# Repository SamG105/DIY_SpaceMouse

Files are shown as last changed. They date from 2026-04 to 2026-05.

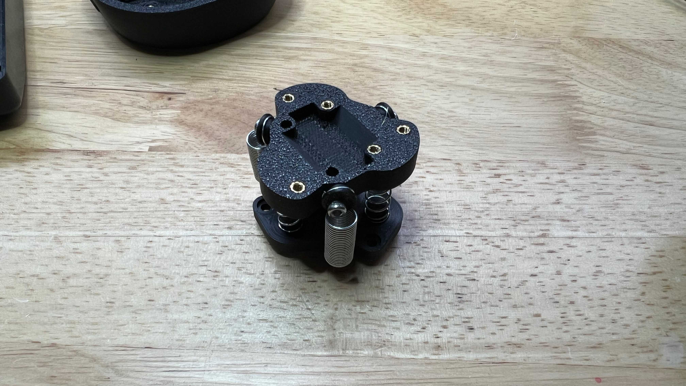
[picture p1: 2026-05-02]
Spacemouse - 1.jpeg

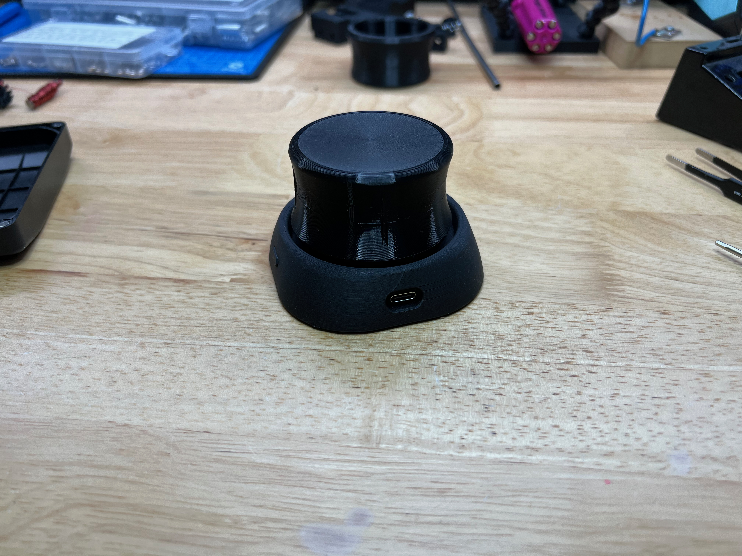
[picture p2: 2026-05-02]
Spacemouse - 2.jpeg

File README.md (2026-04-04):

# DIY SpaceMouse
A DIY SpaceMouse inspired my sb_ocr 's spacemouse build. Altough heavily inspired and based on sb_ocr's work, i designed all the files myself. 

I designed this to make the top "cap" less tall and to accomodate the Seeed studio Xiao RP2040 microcontroller as that's what i could get my hands on. I also changed the code to be purely rotation and zoom as the magnetic sensor (the TLV493D) doesn't have enough DOF to track the full pitch, yaw, roll, zoom, and pan. The code currently only measures zoom, pitch and yaw, which I have found to be the most important movements to replicate.

PLease note that the code is still a work in progress at this point. The buttons still need work to get working reliably and I've started to implement the code to make my DIY spacemouse compatible with the official spacemouse driver.

The hardware required other than the 3d prints is:
•16x M2.5 X 6mm screws
•2x M2.5 X 4mm screws
•2x 10X3mm magnets
•3x 7.14X19.05mm compression springs
•3x 7.93X28.5mm extension springs
•18x M2.5X3.5X4mm heatset inserts

Electronics:
•Seeed Xiao RP2040
•TLV439D sensor
•2x "long" tactile switches

Assembly is fairly straitfoward, simply add threaded inserts (be carefull about the side for the magnetic sensor, it only has two screws that go on one side) and then assemble like the 3d model.

I used the Arduino IDE to flash the code. you will need the "Arduino Mbed OS RP2040 Boards" Package by the official Arduino account.

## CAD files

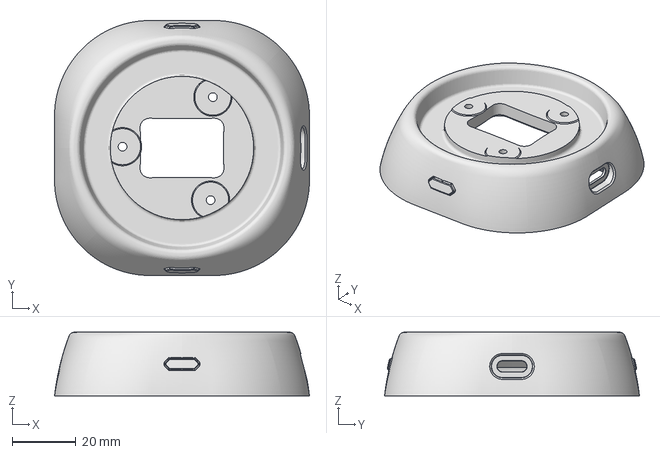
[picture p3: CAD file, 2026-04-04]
3D_Model/print files/Base/Base_body.3mf
80.0 x 80.0 x 20.0 mm

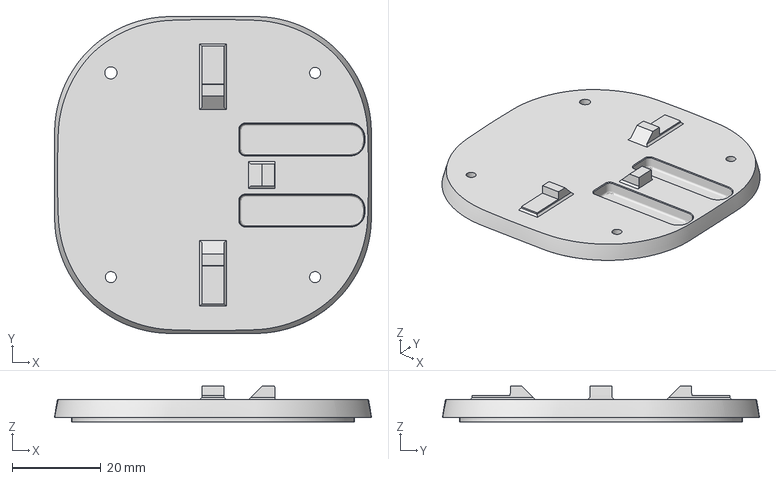
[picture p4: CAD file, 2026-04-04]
3D_Model/print files/Base/Bottom cover.3mf
71.4 x 71.4 x 8.00 mm

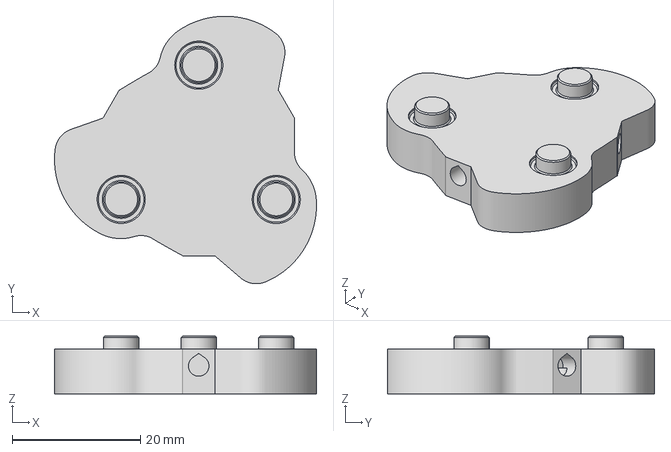
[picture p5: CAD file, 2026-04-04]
3D_Model/print files/Top cap/Bottom spring support plate.3mf
40.8 x 41.7 x 9.00 mm

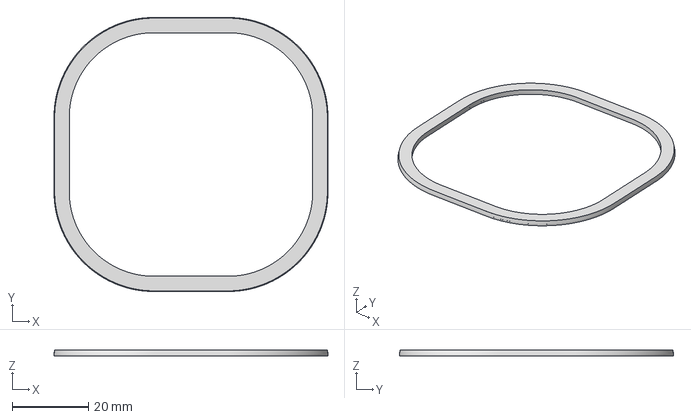
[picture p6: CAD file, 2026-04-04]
3D_Model/print files/Base/TPU anti-skid ring.3mf
71.7 x 71.7 x 1.50 mm

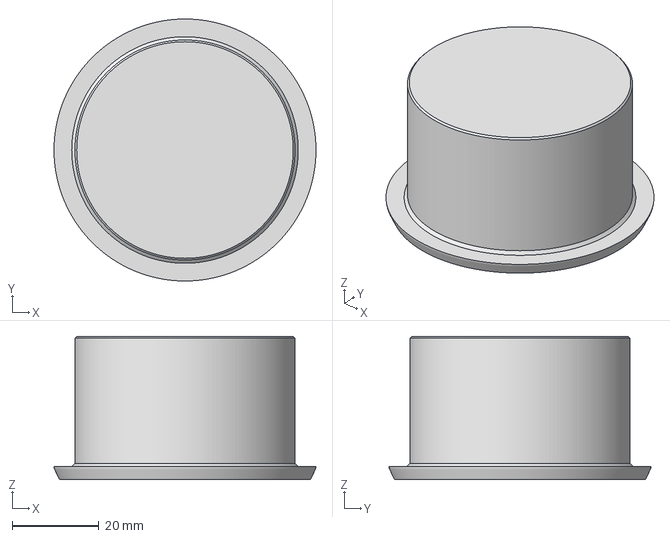
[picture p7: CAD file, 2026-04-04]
3D_Model/print files/Top cap/Inner structure.3mf
60.5 x 60.5 x 33.0 mm

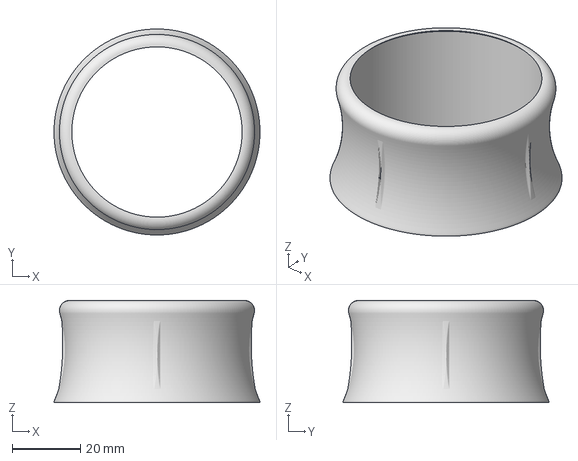
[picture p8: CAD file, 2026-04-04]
3D_Model/print files/Top cap/TPU_exterior.3mf
60.5 x 60.5 x 30.0 mm

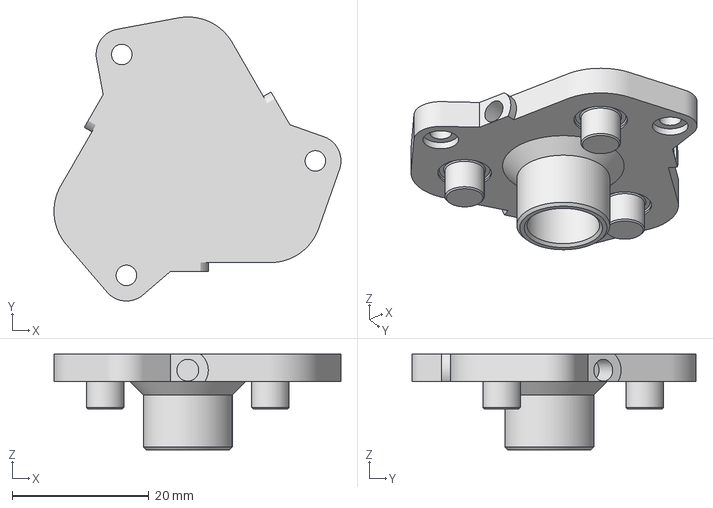
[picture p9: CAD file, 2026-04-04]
3D_Model/print files/Top cap/Top spring support plate.3mf
42.0 x 41.6 x 14.0 mm

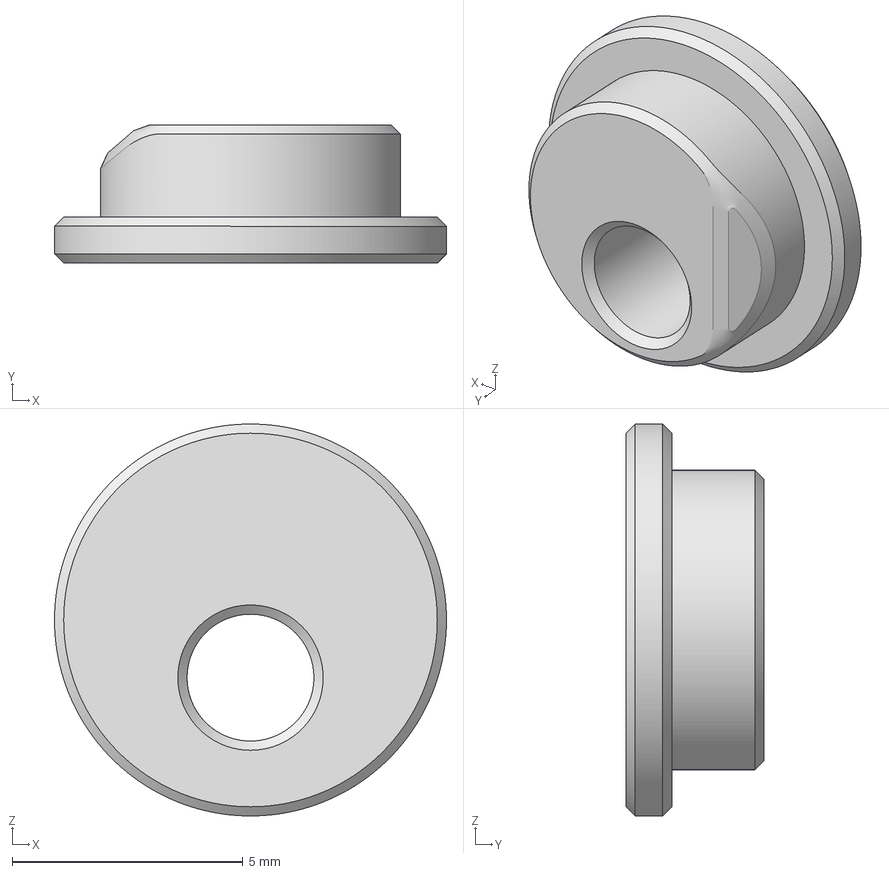
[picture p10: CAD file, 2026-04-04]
3D_Model/print files/Top cap/top spring washer.3mf
8.50 x 3.00 x 8.50 mm

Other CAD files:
3D_Model/Spacemouse_3D_model.f3z

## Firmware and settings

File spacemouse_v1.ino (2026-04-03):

#include <OneButton.h>
#include <Keyboard.h>
#include <Mouse.h>
#include <SimpleKalmanFilter.h>
#include <TLx493D_inc.hpp>

// Definitions for the magnetometer
using namespace ifx::tlx493d;

  //Definition of the pwoer pin and sensor object
const uint8_t POWER_PIN = 7;
TLx493D_A1B6 mag(Wire, TLx493D_IIC_ADDR_A0_e);

//define the kalman filter
SimpleKalmanFilter xFilter(.3,.5,0.1), yFilter(.3,.5,0.1), zFilter(.3,.5,0.1);

//Definitions for the buttons
#define BUTTON_1_PIN 1
#define BUTTON_2_PIN 2

  // define button objects
OneButton button_1;
OneButton button_2;

// global variables
float xHome = 0, yHome = 0, zHome = 0;
float x = 0, y = 0, z = 0;

// constants
const float xyDeadzone = .3;
const float zDeadzone = .15;
const float zThreshold = .5;
int calibrationSamples = 300;
bool isOrbit = false;
double sensitivity = 0.25;
double zSensitivity = 1;

//range of the mag
int magRange = 10;
//range fo the HID report
int HIDRange = 127;

bool movementActive = false;

void setup() {
  Serial.begin(115200);
  delay(50);

  //Setup for the magnetometer
  mag.setPowerPin(POWER_PIN, OUTPUT, INPUT, LOW, HIGH, 1000, 250000);
  mag.begin();
  mag.setSensitivity(TLx493D_SHORT_RANGE_e);
  

  //Setup for the buttons
  button_1.setup(BUTTON_1_PIN, INPUT_PULLUP, true);
  button_2.setup(BUTTON_2_PIN, INPUT_PULLUP, true);
  //Attaching the clicks
  button_1.attachClick(goHome);
  button_1.attachDoubleClick(goHome);

  button_2.attachClick(fitToScreen);
  button_2.attachDoubleClick(fitToScreen);

  //Basic calibration to find center point of mouse
  for (int i = 0; i < calibrationSamples; i++) {
    double xRaw, yRaw, zRaw;
    mag.getMagneticField(&xRaw, &yRaw, &zRaw);
    //mag.printRegisters();

    // to eventually average
    xHome += float(xRaw);
    yHome += float(yRaw);
    zHome += float(zRaw);

    Serial.print(".");
  }

  //average measurments
  xHome = xHome / calibrationSamples;
  yHome = yHome / calibrationSamples;
  zHome = zHome / calibrationSamples;

  Serial.println();
  Serial.println(xHome);
  Serial.println(yHome);
  Serial.println(zHome);

  //Initialize keyboard and mouse
  Keyboard.begin();
  Mouse.begin();
  
}

void loop() {
  //run the buttons at the start of the loop
  button_1.tick();
  button_2.tick();

  //To store new data from mag
  double xRaw, yRaw, zRaw;

  //get new data
  if (!mag.getMagneticField(&xRaw, &yRaw, &zRaw)) {
    Serial.println("error while getting data");
  }

  //Update the filters
  x = xFilter.updateEstimate(float(xRaw) - xHome);
  y = yFilter.updateEstimate(float(yRaw) - yHome);
  z = zFilter.updateEstimate(float(zRaw) - zHome);

  applyDeadzonef(&x, &y, &z);

  if (abs(x) > 0 || abs(y) > 0) {
    // Start of movement → press keys only once
    if (!movementActive) {
      Keyboard.press(KEY_LEFT_SHIFT);
      Mouse.press(MOUSE_MIDDLE);
      movementActive = true;
      Serial.println("Movement started - keys pressed");
    }

    // Send mouse movement every loop (this is what you want while moving)
    double xMove = map(x, -magRange, magRange, -HIDRange, HIDRange);
    double yMove = map(y, -magRange, magRange, -HIDRange, HIDRange);

    Mouse.move(xMove * sensitivity, yMove * sensitivity, 0);
  } 
  else {
    // End of movement → release keys only once
    if (movementActive) {
      Mouse.release(MOUSE_MIDDLE);
      Keyboard.releaseAll();
      movementActive = false;
      Serial.println("Movement ended - keys released");
    }
  }
  // === Z-axis Zoom (independent vertical scroll) ===
  if (abs(z) > 0) {
    double zMove = map(z, -magRange, magRange, -HIDRange, HIDRange);
    Mouse.move(0, 0, -(zMove * zSensitivity));   // wheel = third parameter
  }
  // Optional: small delay if you need to reduce CPU usage / USB traffic
  // delay(5);   // uncomment and tune if needed
}

//BUtton press actions
void goHome() {

}

void fitToScreen() {
  Mouse.click(MOUSE_MIDDLE);
  delay(80);
  Mouse.click(MOUSE_MIDDLE);
}

void applyDeadzone(double *x, double *y, double *z) {
    if (abs(*x) < xyDeadzone) *x = 0.0;
    if (abs(*y) < xyDeadzone) *y = 0.0;
    if (abs(*z) < zDeadzone)  *z = 0.0;
}
void applyDeadzonef(float *x, float *y, float *z) {
    if (fabsf(*x) < xyDeadzone) *x = 0.0f;
    if (fabsf(*y) < xyDeadzone) *y = 0.0f;
    if (fabsf(*z) < zDeadzone)  *z = 0.0f;
}

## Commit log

2026-04-03 Enhance README with detailed project information
    Expanded the project description, detailing design changes, hardware requirements, and assembly instructions.
2026-04-04 Added Fusion 360 model via upload
    [Spacemouse_3D_model.f3z]
2026-04-04 added 3mf files
    [Base_body.3mf, Bottom cover.3mf, Bottom spring support plate.3mf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]
